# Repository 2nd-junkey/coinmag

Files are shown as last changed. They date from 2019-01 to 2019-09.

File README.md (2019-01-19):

# coinmag
for all soldiers

## 概要
弾倉みたいなコインケースが無いなら自分で作ればいいじゃない。  
と言う訳で3Dプリンターさえあれば自分で作れるようにしてみた。  
基本単位は棒金(50枚入り)で1ケース。  
基本用途はコミケのようなイベントと参拝用5円玉。

## 基本構造
- roll  
    本体。主にこれを調整する。
- hook  
    下からコインを支える。
- lid  
    蓋。

## 必要なもの
作成
- 3Dプリンターとその環境(`.stl`が刷れるもの)

調整
- `.stl`ファイルが編集可能(オブジェクトの引き算)が出来るソフト

## 流れ
印刷したい物が登録されている場合
- 目的のデータをダウンロードする。
- 印刷して組み合わせる。
- 完成。

印刷したい物が登録されていない場合
- rollデータをダウンロードする。
- 棒金データを作る。  
  厚みやサイズはセルフサービスとなっております。
- rollデータから棒金データを引き算。
- 印刷してテスト。
- 問題無く入れて取り出せれば完成。  
  ダメなら再調整。
- (上手くいったら追加してプルリクを投げていただけると幸いです。)

## ディレクトリ構成
- .  
    ここ。
    READMEと本体以外の共有パーツ置き場。
- roll  
    棒金のサンプルと対応する本体データ置き場。  
    ご自由に持って行ってください。  
    お代は使用感想や疑問・要望でお願いします。

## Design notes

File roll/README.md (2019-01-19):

# roll
本体部分のデータ置き場。  

とりあえず日本国硬貨で作成予定。
個人的に500円、100円、5円から作成。

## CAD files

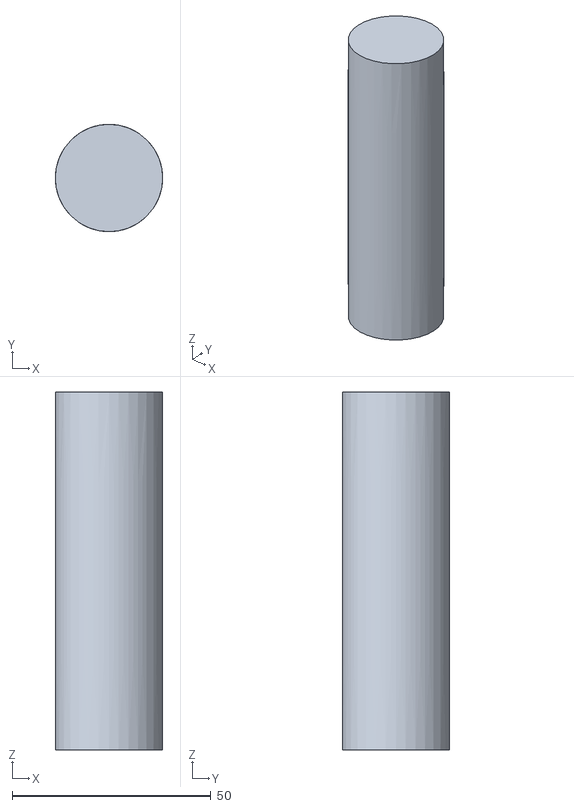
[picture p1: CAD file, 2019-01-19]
roll/500/500yen.stl
27.0 x 27.0 x 90.0

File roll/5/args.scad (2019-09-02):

// coin
coin_radius = 22 / 2;
coin_thickness = 1.55;
coin_numbers = 5;
coin_height = coin_thickness * coin_numbers;

// case
case_radius = 30 / 2;
case_height = 94/5;
key_thickness = 2.5;

// shovel
shovel_coin_numbers = 5;
shovel_bottom = 2;

// tolerances
coin_tolerance = 1;
case_tolerance = 4;
filer_tolerance = 1;
key_tolerance = 1;

// chember
case_hole_radius = case_radius + case_tolerance / 2;
case_hole_height = case_height + case_tolerance;
chember_radius = case_hole_radius + coin_thickness * 2;

// filer
filer_radius = case_radius + filer_tolerance;
filer_height = case_height;

filer_hole_radius = coin_radius + filer_tolerance;

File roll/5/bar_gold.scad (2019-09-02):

include <args.scad>

cylinder(h = coin_height, r = coin_radius, center = false);

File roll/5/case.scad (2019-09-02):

include <args.scad>

coin_insert_radius = coin_radius + coin_tolerance / 2;

// main frame
difference(){
    union(){
        difference(){
            cylinder(h = case_height, r = case_radius, center = true);
            translate([0, case_radius/2, 0]){
                cube([case_radius*2, case_radius, case_height*2], center = true);
            }
            cylinder(h = coin_height, r = coin_insert_radius, center = true);
        }
        translate([0, 0, coin_height/2]){
            cylinder(h = (case_height - coin_height)/2, r = coin_insert_radius, center = false);
        }
    }
    translate([0, -(case_radius*2)/2, 0]){
        cube([case_radius*2, case_radius, case_height*2], center = true);
    }
}

// strap hole
difference(){
    translate([0, -case_radius/8, -(case_height/2 + coin_thickness*1.5)]){
        cube([case_radius/2, case_radius/4, coin_thickness*3], center=true);
    }
    translate([0, -case_radius/8, -(case_height/2 + coin_thickness/1)]){
        cube([case_radius/4, case_radius/4, coin_thickness*2], center=true);
    }
}

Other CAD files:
roll/5/chember.scad
roll/5/filler.scad
roll/5/key.scad
roll/5/shovel.scad

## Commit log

2019-01-19 誤字修正
2019-01-19 方針策定。
2019-01-19 500円の棒金データを登録。 26.5mm×1.8mmだったので、27.0mm×90mmで一旦作成。
    [500yen.stl]
2019-08-10 5円玉の棒金作成
    [bar_gold.scad]
2019-08-10 5枚単位のスコップ作成
    [shovel.scad]
2019-08-10 ケース試作
    [case.scad]
2019-08-10 厚みの公差修正
    [case.scad]
2019-08-10 半径の公差修正
    [case.scad]
2019-08-10 硬貨安定用の底を追加
    [case.scad]
2019-08-10 勢いで一通り作ったので登録
    [chember.scad, filler.scad, key.scad]
2019-08-11 動かなかったので引っ掛かる部分の補正
    [chember.scad, filler.scad]
2019-08-13 引っ掛からなかったので修正
    [chember.scad]
2019-08-13 引っ張りづらいので紐づけ用の口を作成
    [case.scad]
2019-08-13 コイン取り出し口に段が無かったので追加
    [filler.scad]
2019-09-02 stl要らないなとなったので除外
2019-09-02 変数名を統一
    [bar_gold.scad, case.scad, chember.scad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]
2019-09-02 変更が面倒なのでコンフィグ的なのを作って集約
    [args.scad, bar_gold.scad, case.scad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]
2019-09-02 全部上げると見辛いので適度に再分配
    [args.scad, case.scad, chember.scad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]
2019-09-02 何してるか分からなくなったのでコメント追加
    [case.scad, chember.scad, filler.scad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]
2019-09-02 小ロットで生産確認
    [args.scad, case.scad, chember.scad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]
